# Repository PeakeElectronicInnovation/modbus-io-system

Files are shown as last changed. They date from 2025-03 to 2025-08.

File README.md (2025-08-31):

# Modbus IO System

A comprehensive industrial IoT system for temperature monitoring and control, featuring a central controller with web interface and multiple specialized IO boards for thermocouple measurement.

## System Overview

The Modbus IO System consists of a central **Controller** that manages multiple **IO Boards** via Modbus RTU communication. The system provides real-time temperature monitoring, data logging, alarm management, and a modern web-based dashboard for configuration and monitoring.

## System Components

### 1. Modbus IO Controller
- **MCU**: Raspberry Pi RP2040 (dual-core ARM Cortex-M0+)
- **Storage**: 16MB Flash, 1MB LittleFS filesystem
- **Connectivity**: Ethernet, dual RS485 ports, SD card
- **Features**: Web dashboard, data logging, NTP time sync

### 2. Thermocouple Interface (Isolated)
- **MCU**: AVR64DD32 microcontroller
- **Sensor IC**: MCP9601 (8 channels with fault detection)
- **Features**: Safety-critical standalone operation, open/short circuit detection, galvanic isolation
- **Applications**: Temperature safety cutoff systems, industrial process alarms

### 3. Thermocouple Interface (Non-Isolated)
- **MCU**: AVR64DD32 microcontroller  
- **Sensor IC**: MCP9600 (8 channels, basic functionality)
- **Features**: Safety-critical standalone operation for grounded thermocouples
- **Applications**: Temperature safety systems, laboratory alarms, HVAC safety cutoffs

## Key Features

### Web Dashboard
- Real-time temperature monitoring with interactive charts
- Board configuration and management
- Alarm setup and monitoring
- Data export and analysis tools

### Data Management
- High-resolution temperature logging to SD card
- Configurable recording intervals per channel
- CSV export functionality
- Historical data visualization

### Modbus Integration
- Standard Modbus RTU protocol
- Auto-discovery and configuration
- Support for up to 16 IO boards per RS485 bus
- Comprehensive register mapping

### Safety & Reliability
- **Standalone Operation**: IO boards operate independently for safety-critical applications
- **Autonomous Alarms**: Temperature cutoffs function even if controller connection is lost
- Watchdog timers and error recovery
- Power supply monitoring
- Communication fault detection
- Configuration backup and restore

## Quick Start

1. **Power the system** - Connect 24V power supply to controller
2. **Network setup** - Connect Ethernet cable and access web interface
3. **Add IO boards** - Connect boards via RS485 and use auto-discovery
4. **Configure channels** - Set thermocouple types, alarms, and recording preferences
5. **Monitor data** - View real-time temperatures and historical trends

## Technical Specifications

| Component | Controller | TC Interface | TC Non-Isolated |
|---|---|---|---|
| MCU | RP2040 @ 250MHz | AVR64DD32 @ 24MHz | AVR64DD32 @ 24MHz |
| Flash | 16MB | 64KB | 64KB |
| RAM | 264KB | 8KB | 8KB |
| Channels | - | 8 TC inputs | 8 TC inputs |
| Isolation | - | Galvanic | None |
| Fault Detection | - | Open/Short | None |
| Power | 24V | 24V | 24V |

## Development

Each component is a separate PlatformIO project:
- `modbus-io-controller/` - Main controller firmware
- `modbus-io-thermocouple-interface/` - Isolated TC board firmware  
- `modbus-io-thermocouple-non-isolated-interface/` - Non-isolated TC board firmware

## License

Copyright © 2025 Peake Electronic Innovation. All rights reserved.

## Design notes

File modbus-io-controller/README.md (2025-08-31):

# Modbus IO Controller

The central hub of the Modbus IO System, built around the Raspberry Pi RP2040 microcontroller. This controller manages multiple IO boards via dual RS485 buses and provides a comprehensive web interface for system monitoring and configuration.

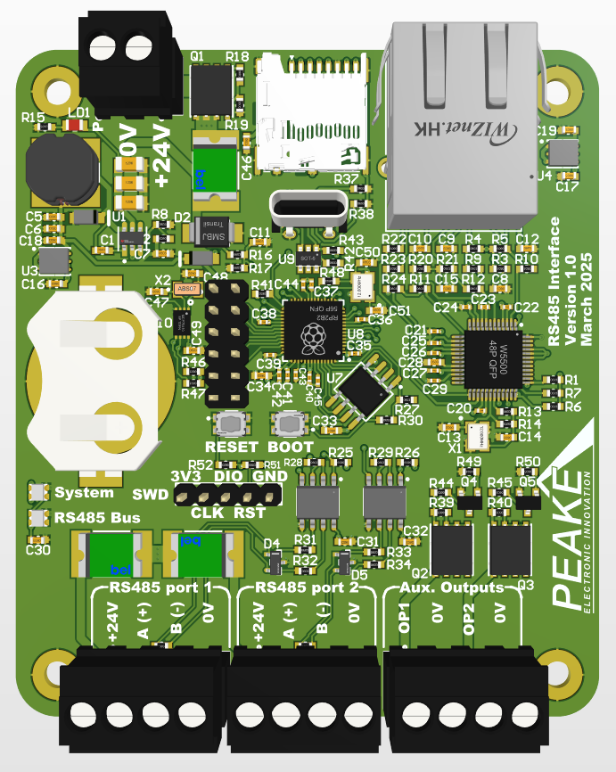
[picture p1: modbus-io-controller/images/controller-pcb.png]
Controller PCB


## Overview

The Modbus IO Controller serves as the master device in a distributed IO system, coordinating communication with up to 32 slave devices across two independent RS485 networks. It features a modern web interface, data logging capabilities, and robust networking features.

## Hardware Specifications

### Microcontroller
- **MCU**: Raspberry Pi RP2040
- **Architecture**: Dual-core ARM Cortex-M0+ @ 250MHz
- **Flash Memory**: 16MB (W25Q128)
- **RAM**: 264KB SRAM
- **Filesystem**: 1MB LittleFS partition

### Connectivity
- **Ethernet**: W5500 controller with RJ45 connector
- **RS485**: Dual isolated ports with automatic direction control
- **USB**: USB-C connector for programming and debugging
- **SD Card**: MicroSD slot for data logging

### Power System
- **Input**: 24VDC via terminal block
- **Regulation**: Switching regulator to 3.3V
- **Monitoring**: Voltage feedback with over/under voltage detection
- **Consumption**: ~2W typical operation

### Indicators
- **Status LEDs**: 2x WS2812B RGB LEDs for system and communication status
- **Power LED**: Green LED for power indication

## Key Features

### Web Interface
- **Dashboard**: Real-time temperature monitoring with interactive charts
- **Configuration**: Board management, channel setup, alarm configuration
- **Data Export**: CSV download of historical data
- **System Settings**: Network configuration, time sync
- **Responsive Design**: Works on desktop, tablet, and mobile devices

### Data Logging
- **Storage**: High-capacity SD card support (up to 32GB)
- **Format**: CSV files with timestamp, board ID, channel, temperature
- **Intervals**: Configurable per channel (1 second to 24 hours)
- **Management**: Automatic file rotation and storage monitoring

### Network Features
- **DHCP/Static IP**: Automatic or manual network configuration
- **NTP Sync**: Automatic time synchronization
- **mDNS**: Device discovery via hostname.local

### Modbus Management
- **Auto-Discovery**: Automatic detection of connected IO boards
- **Configuration**: Web-based setup of board parameters
- **Monitoring**: Real-time communication status and error detection
- **Addressing**: Automatic slave ID assignment and conflict resolution

## Software Architecture

### Dual-Core Design
- **Core 0**: Network management, web server, Modbus TCP
- **Core 1**: IO management, data logging, system monitoring

### Key Modules
- **Network Manager**: Ethernet, WiFi, and protocol handling
- **IO Core**: Board discovery, configuration, and data collection
- **Storage Manager**: SD card operations and data logging
- **Time Manager**: NTP synchronization and RTC management
- **Power Manager**: Voltage monitoring and power state management

## Pin Configuration

### RS485 Interfaces
- **Bus 1**: GPIO pins for UART1 with automatic DE/RE control
- **Bus 2**: GPIO pins for UART2 with automatic DE/RE control

### System Interfaces
- **I2C**: Real-time clock (MCP79410) communication
- **SPI**: Ethernet controller and SD card interfaces
- **Status LEDs**: WS2812B data line
- **Power Monitor**: ADC input for voltage feedback

## Development Setup

### Prerequisites
- PlatformIO IDE or CLI
- USB-C cable for programming
- 24V power supply for testing

### Build Process
```bash
# Clone repository
git clone <repository-url>
cd modbus-io-system/modbus-io-controller

# Build firmware
pio run

# Build filesystem image
pio run -t buildfs

# Upload firmware
pio run -t upload

# Upload filesystem
pio run -t uploadfs
```

### Web Asset Optimization
The build process includes automatic minification of web assets:
- **JavaScript**: Minified from 137KB to 18KB
- **HTML**: Compressed from 35KB to 13KB  
- **Charts**: Custom lightweight SVG implementation (14KB vs 207KB Chart.js)

## Configuration

### Network Setup
Access the web interface at the device IP address. Default configuration:
- **DHCP**: Enabled by default
- **Fallback IP**: 192.168.1.100
- **Hostname**: modbus-controller.local

### Board Management
1. Connect IO boards via RS485
2. Use "Scan for Boards" in web interface
3. Configure board settings and channel parameters
4. Enable data logging as needed

## Troubleshooting

### Common Issues
- **No web interface**: Check Ethernet connection and IP configuration
- **Board not detected**: Verify RS485 wiring and termination
- **Data logging fails**: Check SD card insertion and formatting
- **Time sync issues**: Verify NTP server accessibility

### LED Status Indicators
- **Status LED** (LED 1):
  - Green: System OK
  - Red: System error
  - Blue: Unconfigured
  - Orange: Warning
- **Communication LED** (LED 2):
  - Green: Active communication
  - Red: Communication error
  - Off: No activity

## Technical Notes

### Memory Optimization
The system implements advanced memory management techniques:
- **Binary Configuration Storage**: 90% reduction in RAM usage
- **Compressed Web Assets**: 88% reduction in flash usage
- **Efficient Data Structures**: Optimized for RP2040 constraints

### Performance
- **Scan Rate**: Up to 100Hz per channel depending on configuration
- **Web Response**: <100ms for most operations
- **Data Logging**: Sustained 1MB/hour with 32 channels @ 1Hz

## Hardware Revision

**Current Version**: v1.0 (March 2025)
- Initial production release
- Optimized power supply design
- Enhanced EMI protection

## Support

For technical support and documentation updates, contact Peake Electronic Innovation.

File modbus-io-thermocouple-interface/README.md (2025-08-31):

# Thermocouple Interface (Isolated)

An 8-channel thermocouple measurement board with galvanic isolation and advanced fault detection capabilities. Built around the AVR64DD32 microcontroller and MCP9601 thermocouple-to-digital converters.

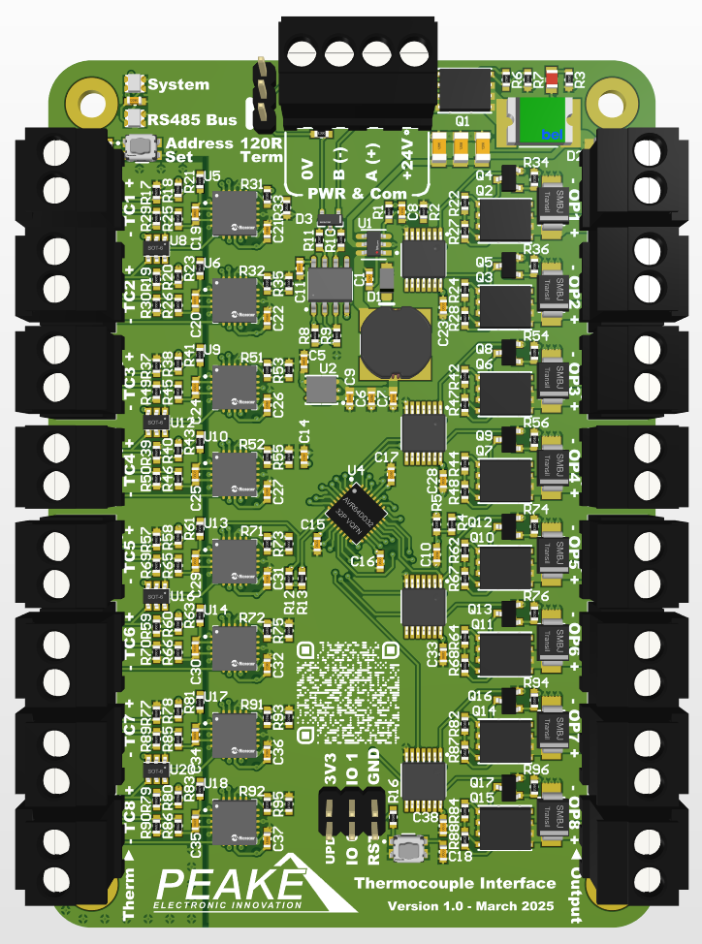
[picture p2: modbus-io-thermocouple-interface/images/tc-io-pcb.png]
Thermocouple Interface PCB


## Overview

This board provides high-accuracy thermocouple measurement with comprehensive fault detection for safety-critical industrial applications. **The board operates autonomously** - once configured, it continues to provide temperature monitoring and safety cutoffs even if communication with the controller is lost. Each channel features galvanic isolation and can detect open circuits, short circuits, and provide temperature alarms with configurable setpoints.

## Hardware Specifications

### Microcontroller
- **MCU**: AVR64DD32 (64KB Flash, 8KB RAM)
- **Architecture**: 8-bit AVR @ 24MHz
- **Communication**: Modbus RTU slave via RS485
- **Programming**: UPDI interface

### Thermocouple Interface
- **IC**: MCP9601 (8 channels)
- **Resolution**: 0.0625°C (16-bit)
- **Accuracy**: ±1.5°C (typical)
- **Cold Junction**: Integrated compensation
- **Sampling Rate**: Up to 4 samples/second per channel

### Supported Thermocouple Types
- **Type K**: -200°C to +1372°C
- **Type J**: -210°C to +1200°C  
- **Type T**: -200°C to +400°C
- **Type N**: -200°C to +1300°C
- **Type S**: -50°C to +1768°C
- **Type E**: -200°C to +1000°C
- **Type B**: +250°C to +1820°C
- **Type R**: -50°C to +1768°C

### Fault Detection
- **Open Circuit**: Detects broken or disconnected thermocouples
- **Short Circuit**: Detects shorted thermocouple inputs
- **Over/Under Range**: Temperature readings outside sensor limits
- **Communication**: I2C bus error detection

### Power System
- **Input**: 24VDC via terminal block
- **Isolation**: Galvanic isolation between measurement and digital circuits
- **Consumption**: ~3W typical operation
- **Protection**: Reverse polarity and overvoltage protection

## Key Features

### Advanced Measurement
- **Multi-Type Support**: All standard thermocouple types
- **Auto-Calibration**: Automatic cold junction compensation
- **High Resolution**: 16-bit ADC with 0.0625°C resolution
- **Fast Response**: Configurable sampling rates up to 4Hz

### Alarm Management
- **Configurable Setpoints**: Per-channel temperature alarms
- **Hysteresis**: Prevents alarm chatter
- **Latch/Auto-Clear**: Configurable alarm behavior
- **Rising/Falling Edge**: Configurable alarm direction

### Safety Output Control
- **8 Relay Outputs**: One per thermocouple channel for safety cutoffs
- **Autonomous Operation**: Outputs function independently of controller connection
- **Alarm Driven**: Automatic safety cutoffs based on temperature thresholds
- **Manual Override**: Direct control via Modbus commands when connected
- **Feedback**: Output state monitoring

### Status Indication
- **Dual LEDs**: WS2812B RGB LEDs for status and communication
- **Visual Feedback**: Color-coded status indication
- **Address Button**: Manual Modbus address configuration

## Modbus Register Map

### Input Registers (Read-Only)
| Address | Description | Units | Range |
|---|---|---|---|
| 0-7 | Channel 0-7 Temperature | 0.1°C | -2000 to +15000 |
| 8-15 | Channel 0-7 Cold Junction | 0.1°C | -400 to +1250 |
| 16-23 | Channel 0-7 Delta Temperature | 0.1°C | -2000 to +15000 |

### Holding Registers (Read/Write)
| Address | Description | Units | Range |
|---|---|---|---|
| 0 | Status Register | Bitmap | - |
| 1 | Board Type ID | - | 0x0002 |
| 2 | Slave ID | - | 1-244 |
| 3-10 | Channel 0-7 TC Type | - | 0-7 |
| 11-18 | Channel 0-7 Alert Setpoint | 0.1°C | -400 to +15000 |
| 19-26 | Channel 0-7 Alert Hysteresis | 0.1°C | 0-255 |
| 27-42 | Board Name | ASCII | 32 chars |

### Coils (Read/Write)
| Address | Description |
|---|---|
| 0-7 | Channel 0-7 Output Enable |
| 8-15 | Channel 0-7 Alert Enable |
| 16-23 | Channel 0-7 Alert Latch |
| 24-31 | Channel 0-7 Alert Edge |
| 32-39 | Channel 0-7 Latch Reset |

### Discrete Inputs (Read-Only)
| Address | Description |
|---|---|
| 0-7 | Channel 0-7 Output State |
| 8-15 | Channel 0-7 Alert State |
| 16-23 | Channel 0-7 Open Circuit |
| 24-31 | Channel 0-7 Short Circuit |

## Configuration

### Initial Setup
1. **Power Connection**: Apply 24VDC to power terminals
2. **RS485 Connection**: Connect to Modbus master via A/B terminals
3. **Address Assignment**: Hold address button for 3 seconds to enter config mode
4. **Thermocouple Connection**: Connect thermocouples to TC0-TC7 terminals

### Channel Configuration
Each channel can be independently configured:
- **Thermocouple Type**: Select appropriate type for sensor
- **Alert Setpoint**: Temperature threshold for alarm
- **Alert Hysteresis**: Deadband to prevent chatter
- **Output Control**: Enable/disable relay output
- **Alarm Behavior**: Latch or auto-clear, rising or falling edge

### EEPROM Storage
Configuration is automatically saved to EEPROM:
- **Address 0**: Validation byte (0xAA)
- **Address 1-12**: Modbus configuration
- **Address 16-95**: Thermocouple channel configurations

## Development

### Build Environment
```bash
# Navigate to project directory
cd modbus-io-thermocouple-interface

# Build firmware
pio run -e Upload_UPDI

# Upload via UPDI programmer
pio run -e Upload_UPDI -t upload
```

### Programming Interface
- **UPDI**: Single-wire programming interface
- **Programmer**: Atmel-ICE or compatible
- **Bootloader**: Optional UART bootloader support

### Debug Features
- **Serial Output**: 115200 baud debug information
- **Status Monitoring**: Real-time system status via serial
- **Configuration Echo**: Displays loaded configuration on startup

## Installation

### Mechanical
- **Mounting**: 4x M3 mounting holes
- **Enclosure**: DIN rail compatible housing
- **Dimensions**: 100mm x 80mm PCB

### Electrical
- **Power**: 24VDC ±10% via screw terminals
- **RS485**: 2-wire interface with 120Ω termination
- **Thermocouples**: Standard miniature connectors
- **Outputs**: Relay contacts rated for 250VAC/5A

## Safety Considerations

### Isolation
- **Galvanic Isolation**: Complete isolation between measurement and communication
- **Voltage Rating**: 1000V isolation barrier
- **Safety Standards**: Designed for industrial safety requirements

### Fault Protection
- **Input Protection**: ESD protection on all thermocouple inputs
- **Power Protection**: Reverse polarity and overvoltage protection
- **Thermal Protection**: Automatic shutdown on overtemperature

## Troubleshooting

### LED Status Codes
- **Status LED** (LED 1):
  - **Solid Green**: System OK, Modbus configured
  - **Pulsing Red**: System error (I2C, power, etc.)
  - **Pulsing Blue**: Unconfigured, waiting for address assignment
- **Communication LED** (LED 2):
  - **Brief Green**: Successful Modbus communication
  - **Brief Red**: Modbus communication error
  - **Off**: No communication activity

### Common Issues
- **No temperature reading**: Check thermocouple connections and type setting
- **Open circuit fault**: Verify thermocouple continuity
- **Communication timeout**: Check RS485 wiring and termination
- **Address conflicts**: Use address button to reconfigure slave ID

## Hardware Revision

**Current Version**: v1.0 (March 2025)
- Initial production release
- MCP9601 with full fault detection
- Galvanic isolation design
- Enhanced EMI filtering

## Applications

### Safety-Critical Industrial Applications
- **Furnace Safety Systems**: Emergency shutdown on overtemperature
- **Chemical Process Safety**: Autonomous temperature monitoring and cutoffs
- **Heat Treatment Control**: Independent safety interlocks
- **Boiler Protection**: Steam system safety shutdowns

### Laboratory Equipment
- Research instrumentation
- Calibration systems
- Environmental chambers
- Materials testing

## Technical Support

For technical support, schematic information, and application notes, contact Peake Electronic Innovation.

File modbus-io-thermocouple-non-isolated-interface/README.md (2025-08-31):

# Thermocouple Interface (Non-Isolated)

An 8-channel thermocouple measurement board designed for cost-effective temperature monitoring with grounded thermocouples. Built around the AVR64DD32 microcontroller and MCP9600 thermocouple-to-digital converters.

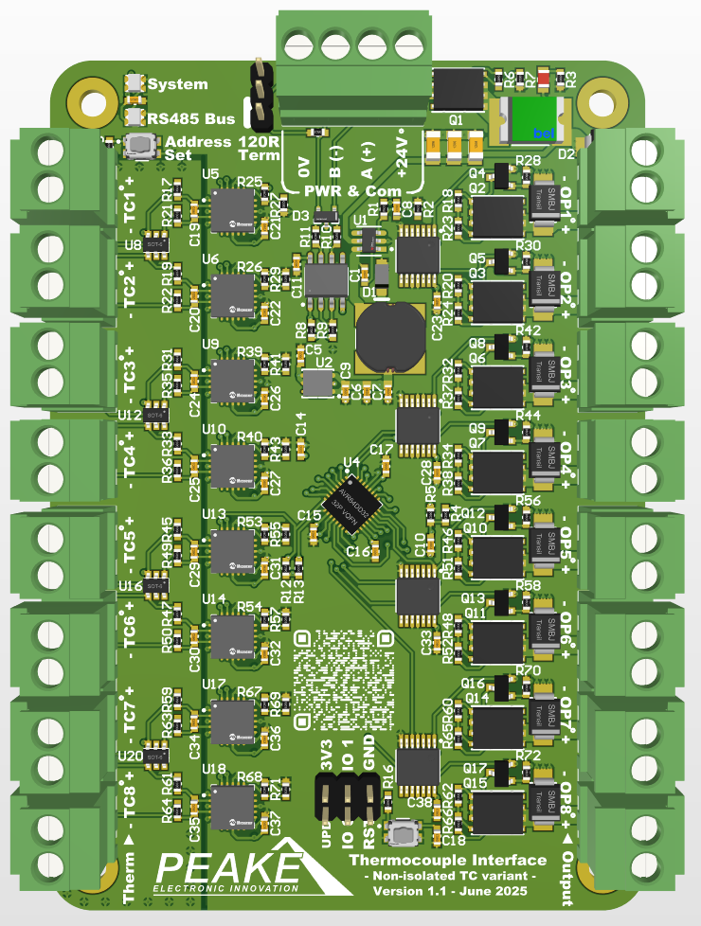
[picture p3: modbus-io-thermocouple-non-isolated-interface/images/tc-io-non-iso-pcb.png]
Thermocouple Non-Isolated Interface PCB


## Overview

This board provides accurate thermocouple measurement for safety-critical applications where galvanic isolation is not required. **The board operates autonomously** - once configured, it continues to provide temperature monitoring and safety cutoffs even if communication with the controller is lost. It's optimized for grounded thermocouple systems and offers the same measurement capabilities as the isolated version but without fault detection, making it ideal for laboratory and HVAC safety applications.

## Hardware Specifications

### Microcontroller
- **MCU**: AVR64DD32 (64KB Flash, 8KB RAM)
- **Architecture**: 8-bit AVR @ 24MHz
- **Communication**: Modbus RTU slave via RS485
- **Programming**: UPDI interface

### Thermocouple Interface
- **IC**: MCP9600 (8 channels)
- **Resolution**: 0.0625°C (16-bit)
- **Accuracy**: ±1.5°C (typical)
- **Cold Junction**: Integrated compensation
- **Sampling Rate**: Up to 4 samples/second per channel

### Supported Thermocouple Types
- **Type K**: -200°C to +1372°C
- **Type J**: -210°C to +1200°C  
- **Type T**: -200°C to +400°C
- **Type N**: -200°C to +1300°C
- **Type S**: -50°C to +1768°C
- **Type E**: -200°C to +1000°C
- **Type B**: +250°C to +1820°C
- **Type R**: -50°C to +1768°C

### Key Differences from Isolated Version
- **No Galvanic Isolation**: Direct connection to measurement circuits
- **No Fault Detection**: Cannot detect open or short circuits
- **MCP9600 IC**: Basic thermocouple converter without fault detection
- **Grounded TC Compatible**: Suitable for grounded thermocouple applications
- **Lower Cost**: Simplified design reduces manufacturing cost

### Power System
- **Input**: 24VDC via terminal block
- **Consumption**: ~2.5W typical operation
- **Protection**: Reverse polarity and overvoltage protection

## Key Features

### Temperature Measurement
- **Multi-Type Support**: All standard thermocouple types
- **Auto-Calibration**: Automatic cold junction compensation
- **High Resolution**: 16-bit ADC with 0.0625°C resolution
- **Fast Response**: Configurable sampling rates up to 4Hz

### Alarm Management
- **Configurable Setpoints**: Per-channel temperature alarms
- **Hysteresis**: Prevents alarm chatter
- **Latch/Auto-Clear**: Configurable alarm behavior
- **Rising/Falling Edge**: Configurable alarm direction

### Safety Output Control
- **8 Relay Outputs**: One per thermocouple channel for safety cutoffs
- **Autonomous Operation**: Outputs function independently of controller connection
- **Alarm Driven**: Automatic safety cutoffs based on temperature thresholds
- **Manual Override**: Direct control via Modbus commands when connected
- **Feedback**: Output state monitoring

### Status Indication
- **Dual LEDs**: WS2812B RGB LEDs for status and communication
- **Visual Feedback**: Color-coded status indication
- **Address Button**: Manual Modbus address configuration

## Modbus Register Map

### Input Registers (Read-Only)
| Address | Description | Units | Range |
|---|---|---|---|
| 0-7 | Channel 0-7 Temperature | 0.1°C | -2000 to +15000 |
| 8-15 | Channel 0-7 Cold Junction | 0.1°C | -400 to +1250 |
| 16-23 | Channel 0-7 Delta Temperature | 0.1°C | -2000 to +15000 |

### Holding Registers (Read/Write)
| Address | Description | Units | Range |
|---|---|---|---|
| 0 | Status Register | Bitmap | - |
| 1 | Board Type ID | - | 0x0002 |
| 2 | Slave ID | - | 1-244 |
| 3-10 | Channel 0-7 TC Type | - | 0-7 |
| 11-18 | Channel 0-7 Alert Setpoint | 0.1°C | -400 to +15000 |
| 19-26 | Channel 0-7 Alert Hysteresis | 0.1°C | 0-255 |
| 27-42 | Board Name | ASCII | 32 chars |

### Coils (Read/Write)
| Address | Description |
|---|---|
| 0-7 | Channel 0-7 Output Enable |
| 8-15 | Channel 0-7 Alert Enable |
| 16-23 | Channel 0-7 Alert Latch |
| 24-31 | Channel 0-7 Alert Edge |
| 32-39 | Channel 0-7 Latch Reset |

### Discrete Inputs (Read-Only)
| Address | Description |
|---|---|
| 0-7 | Channel 0-7 Output State |
| 8-15 | Channel 0-7 Alert State |
| 16-23 | Reserved (No Open Circuit Detection) |
| 24-31 | Reserved (No Short Circuit Detection) |

## Configuration

### Initial Setup
1. **Power Connection**: Apply 24VDC to power terminals
2. **RS485 Connection**: Connect to Modbus master via A/B terminals
3. **Address Assignment**: Hold address button for 3 seconds to enter config mode
4. **Thermocouple Connection**: Connect grounded thermocouples to TC0-TC7 terminals

### Channel Configuration
Each channel can be independently configured:
- **Thermocouple Type**: Select appropriate type for sensor
- **Alert Setpoint**: Temperature threshold for alarm
- **Alert Hysteresis**: Deadband to prevent chatter
- **Output Control**: Enable/disable relay output
- **Alarm Behavior**: Latch or auto-clear, rising or falling edge

### EEPROM Storage
Configuration is automatically saved to EEPROM:
- **Address 0**: Validation byte (0xAA)
- **Address 1-12**: Modbus configuration
- **Address 16-95**: Thermocouple channel configurations

## Development

### Build Environment
```bash
# Navigate to project directory
cd modbus-io-thermocouple-non-isolated-interface

# Build firmware
pio run -e Upload_UPDI

# Upload via UPDI programmer
pio run -e Upload_UPDI -t upload
```

### Programming Interface
- **UPDI**: Single-wire programming interface
- **Programmer**: Atmel-ICE or compatible
- **Bootloader**: Optional UART bootloader support

### Debug Features
- **Serial Output**: 115200 baud debug information
- **Status Monitoring**: Real-time system status via serial
- **Configuration Echo**: Displays loaded configuration on startup

## Installation

### Mechanical
- **Mounting**: 4x M3 mounting holes
- **Enclosure**: DIN rail compatible housing
- **Dimensions**: 100mm x 80mm PCB

### Electrical
- **Power**: 24VDC ±10% via screw terminals
- **RS485**: 2-wire interface with 120Ω termination
- **Thermocouples**: Standard miniature connectors (grounded types)
- **Outputs**: Relay contacts rated for 250VAC/5A

## Applications

### Laboratory Safety Systems
- **Research Instruments**: Autonomous temperature safety monitoring
- **Calibration Systems**: Independent temperature cutoffs
- **Environmental Chambers**: Safety interlocks for climate control
- **Materials Testing**: Thermal runaway protection

### HVAC Safety Applications
- **Building Automation**: Zone temperature safety cutoffs
- **Boiler Systems**: Independent overtemperature protection
- **Air Handling Units**: Safety shutdowns for supply/return air
- **Heat Exchangers**: Autonomous thermal protection

### Food & Beverage
- **Process Monitoring**: Cooking and pasteurization temperatures
- **Cold Storage**: Refrigeration system monitoring
- **Brewing**: Fermentation temperature control
- **Quality Control**: Product temperature verification

## Limitations

### No Fault Detection
Unlike the isolated version, this board cannot detect:
- Open circuit conditions (broken thermocouples)
- Short circuit conditions (shorted inputs)
- Thermocouple degradation

### Grounding Requirements
- **Common Ground**: All thermocouples must share common ground with system
- **Ground Loops**: Potential for noise in multi-point grounded systems
- **Isolation**: No galvanic isolation between channels

## Troubleshooting

### LED Status Codes
- **Status LED** (LED 1):
  - **Solid Green**: System OK, Modbus configured
  - **Pulsing Red**: System error (I2C, power, etc.)
  - **Pulsing Blue**: Unconfigured, waiting for address assignment
- **Communication LED** (LED 2):
  - **Brief Green**: Successful Modbus communication
  - **Brief Red**: Modbus communication error
  - **Off**: No communication activity

### Common Issues
- **Erratic readings**: Check for ground loops or EMI
- **No temperature reading**: Verify thermocouple type setting
- **Communication timeout**: Check RS485 wiring and termination
- **Address conflicts**: Use address button to reconfigure slave ID

### Grounding Best Practices
- **Single Point Ground**: Connect all thermocouple shields to one point
- **Avoid Ground Loops**: Keep measurement and power grounds separate
- **EMI Protection**: Use shielded cables in high-noise environments

## Hardware Revision

**Current Version**: v1.1 (June 2025)
- Updated from isolated design
- MCP9600 implementation
- Optimized for grounded thermocouple applications
- Cost-reduced design

## Comparison with Isolated Version

| Feature | Isolated (MCP9601) | Non-Isolated (MCP9600) |
|---|---|---|
| Open Circuit Detection | ✓ | ✗ |
| Short Circuit Detection | ✓ | ✗ |
| Galvanic Isolation | ✓ | ✗ |
| Grounded TC Support | Limited | ✓ |
| Cost | Higher | Lower |
| Applications | Industrial | Lab/HVAC |

## Technical Support

For technical support, schematic information, and application notes, contact Peake Electronic Innovation.

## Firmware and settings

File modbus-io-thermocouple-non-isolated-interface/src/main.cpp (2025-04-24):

#include "sys_init.h"

// Early initialization code that runs before main C runtime
void __attribute__((section(".init3"))) early_init(void) {
  // Set all Port A pins high immediately after reset
  PORTA.OUTSET = 0xFF;  // Set all Port A pins high
  PORTA.DIRSET = 0xFF;  // Set all Port A pins as outputs
}

void saveConfig() {
  newDataToSave = false;
  // Save Slave ID and board name to EEPROM
  EEPROM.put(EEPROM_MODBUSCFG_ADDR, modbusHolding.slaveID);
  EEPROM.put(EEPROM_BOARDNAME_ADDR, modbusHolding.boardName);
  // Save thermocouple config to EEPROM
  for(int i = 0; i < 8; i++) {
    EEPROM.put(EEPROM_CONFIG_ADDR + (i * sizeof(tc_config_t)), tcConfig[i]);
  }
}

void getConfig() {
  // EEPROM memory map -----------------------------------------
  // 0 - EEPROM Valid Value (0xAA)
  // 1 - Modbus Config (12 bytes)
  // 16 - MCP960x Config (8 * 10 bytes)
  // -----------------------------------------------------------

  // Read configuration from EEPROM
  uint8_t valid = EEPROM.read(EEPROM_VALID_ADDR);

  // Store defaults if valid byte is not set
  if (valid != EEPROM_VALID_VALUE) {
    Serial.println("Invalid EEPROM data, initializing to default values:");
    saveConfig();
    EEPROM.write(EEPROM_VALID_ADDR, EEPROM_VALID_VALUE);
    Serial.println("Default configuration saved to EEPROM.");
  } else {
     // Load configuration from EEPROM
    Serial.println("Loading previously saved configuration from EEPROM...");
    // Slave ID:
    EEPROM.get(EEPROM_MODBUSCFG_ADDR, modbusHolding.slaveID);
    if (modbusHolding.slaveID < 245 && modbusHolding.slaveID > 0) {
      modbusInitialised = true;
      statusLedColour = LED_OK;
      Serial.printf("Modbus slave ID: %d\n", modbusHolding.slaveID);
    } else {
      statusLedColour = LED_UNCONFIGURED;
      Serial.printf("Modbus unconfigured\n");
    }
    // Board name:
    EEPROM.get(EEPROM_BOARDNAME_ADDR, modbusHolding.boardName);
    Serial.printf("Board name: %s\n", modbusHolding.boardName);
    // Thermocouple config:
    for(int i = 0; i < 8; i++) {
      EEPROM.get(EEPROM_CONFIG_ADDR + (i * sizeof(tc_config_t)), tcConfig[i]);
    }
  }

  // Store config to tc structs and modbus registers
  for(int i = 0; i < 8; i++) {
    tc[i].config.type = static_cast<MCP960x_type_t>(tcConfig[i].type);
    tc[i].config.alertSP[0] = tcConfig[i].alertSP;
    tc[i].config.alertHyst[0] = tcConfig[i].alertHyst;
    tc[i].config.alertEnable[0] = tcConfig[i].alertEnable;
    tc[i].config.alertLatch[0] = tcConfig[i].alertLatch;
    tc[i].config.alertEdge[0] = tcConfig[i].alertEdge;
    modbusHolding.type[i] = static_cast<uint16_t>(tcConfig[i].type);
    modbusHolding.alertSP[i] = tcConfig[i].alertSP;
    modbusHolding.alertHyst[i] = tcConfig[i].alertHyst;
    modbusOutSet.alertEnable[i] = tcConfig[i].alertEnable;
    modbusOutSet.alertLatch[i] = tcConfig[i].alertLatch;
    modbusOutSet.alertEdge[i] = tcConfig[i].alertEdge;
    modbusOutSet.outputEnable[i] = tcConfig[i].outputEnable;

    // Debug print
    Serial.printf("Type: %d, SD: ", modbusHolding.type[i]);
    Serial.print(modbusHolding.alertSP[i]);
    Serial.printf(", Hyst: %d, Enable: %d, Latch: %d, Edge: %d, Output Enable: %d\n", modbusHolding.alertHyst[i], modbusOutSet.alertEnable[i], modbusOutSet.alertLatch[i], modbusOutSet.alertEdge[i], modbusOutSet.outputEnable[i]);
  }
  Serial.printf("modbusHolding.boardType: %d\n", modbusHolding.boardType);
  memcpy(holdingReg, &modbusHolding, sizeof(holdingReg));
  memcpy(coil, &modbusOutSet, sizeof(coil));
  Serial.printf("After memcpy holdingReg[1]: %d\n", holdingReg[1]);
}

void setupModbus() {
  pinMode(PIN_ADDR_BTN, INPUT_PULLUP);
  bus.configureCoils(coil, 40);
  bus.configureDiscreteInputs(inputDiscrete, 32);
  bus.configureHoldingRegisters(holdingReg, 42);
  bus.configureInputRegisters(inputReg, 48);
  if (modbusInitialised) {
    bus.begin(modbusHolding.slaveID, 500000);
    commLedColour = LED_OK;
  } else {
    commLedColour = LED_OFF;
    Serial.println("Modbus not configured, hold Address button for 3 seconds to start configuration.");
  }
  Serial.printf("After setupModbus holdingReg[1]: %d\n", holdingReg[1]);
}

void setupThermocoupleInterface() {
  Wire.pins(PIN_I2C_SDA, PIN_I2C_SCL); // Set I2C pins for Wire library
  Wire.begin(); // Initialize I2C bus
  Wire.setClock(50000);
  bool error = false;
  for (int i = 0; i < 8; i++) {
    uint8_t deviceID = tc[i].begin(); // Initialize each MCP960x thermocouple interface
    if (deviceID == 0) {
      Serial.printf("Failed to initialize MCP960x at address 0x6%x\n", i);
      error = true;
    } else {
      Serial.printf("MCP960x initialized successfully! Device at address 0x6%x has device ID: 0x%02x\n", i, deviceID);
      if (!tc[i].setConfig()) { // Set the configuration for each MCP960x
        Serial.printf("Failed to set configuration for MCP960x at address 0x6%x\n", i);
        error = true;
      } else {
        Serial.printf("Configuration set successfully for MCP960x at address 0x6%x\n", i);
        tc[i].printConfig();
      }
    }
  }
  statusLedColour = error ? LED_ERROR : modbusInitialised ? LED_OK : LED_UNCONFIGURED;

  if (error) {
    Serial.println("Error initializing MCP960x devices. Check connections and power supply.");
    leds.setPixelColor(0, LED_ERROR); // Set the first LED to error color
    leds.show(); // Update the LEDs
    delay(2000);
    _PROTECTED_WRITE(RSTCTRL.SWRR,1);
  }

  // Enable outputs
  for (int i = 0; i < 8; i++) {
    pinMode(enablePin[i], OUTPUT);
    digitalWrite(enablePin[i], !modbusOutSet.outputEnable[i]);
    Serial.printf("Out Enable %d is: %i\n", i, modbusOutSet.outputEnable[i]);
    Serial.printf("Output %d is: %s\n", i, digitalRead(enablePin[i]) ? "HIGH" : "LOW");
  }
}

void readAll() {
  if (!modbusInitialised) return;
  bool error = false;
  // Read data from all MCP9601 ICs and check output states
  for (int i = 0; i < 8; i++) {
    modbusInput.temperature[i] = tc[i].readTemperature();
    modbusInput.coldJunction[i] = tc[i].readColdJunctionTemperature();
    modbusInput.deltaJunction[i] = tc[i].readDeltaTemperature();
    if (tc[i].updateStatus() == 0xFF) error = true;
    modbusFlag.outputState[i] = digitalRead(outputFBpin[i]); // Read the output state from the corresponding pin
    modbusFlag.alertState[i] = tc[i].status.alert[0];
    modbusFlag.openCircuit[i] = tc[i].status.openCircuit;
    modbusFlag.shortCircuit[i] = tc[i].status.shortCircuit;  
  }
  status.I2CError = error;
  // Copy data to modbus registers (read only)
  memcpy(inputDiscrete, &modbusFlag, sizeof(modbusFlag)); // Copy the modbusFlag struct to the inputDiscrete array
  memcpy(inputReg, &modbusInput, sizeof(modbusInput)); // Copy the modbusInput struct to the inputReg array
}

void setupLEDs() {
  // Initialize the LEDs
  leds.begin();
  leds.setBrightness(50); // Set brightness to 50%
  leds.setPixelColor(0, LED_STARTUP); // Set the first LED to the startup color
  leds.setPixelColor(1, LED_OFF); // Set the second LED to off
  leds.show(); // Update the LEDs to show the new colors
  Serial.println("LEDs initialised");
  ledPulseTime = millis() + ledPulseDelay;
}

void setupVPSU() {
  analogReference(PSU_FB_VREF);
  analogReadResolution(12);
}

void handleStatus() {
  holdingReg[0] = (status.PSUvoltage << 4) | (status.PSUError << 2) | (status.I2CError << 1) | status.modbusError;
  uint32_t tempColour = statusLedColour;
  if (status.PSUError || status.I2CError || status.modbusError) tempColour = LED_ERROR;
  if (millis() >= ledPulseTime) {
    if (ledState) leds.setPixelColor(0, LED_OFF);
    else leds.setPixelColor(0, tempColour);
    ledState = !ledState;
    leds.show();
    ledPulseTime += ledPulseDelay;
  }
}

void handleVPSU() {
  int raw = analogRead(PIN_PS_FB);
  float volts = raw * PSU_FB_RAW_TO_V;
  if (volts > PSU_VOLTAGE_MAX || volts < PSU_VOLTAGE_MIN) status.PSUError = true;
  else status.PSUError = false;
  status.PSUvoltage = static_cast<uint16_t>(volts * 10);
}

void handleModbus() {
  if (!modbusInitialised  && !waitingForModbusConfig) return;
  int FC = bus.poll();
  if (FC == 0) {
    if (!waitingForModbusConfig) {
      leds.setPixelColor(1, LED_OFF);
      leds.show();
    }
    return; // No Modbus request received
  }
  if (FC < 0) {
    Serial.printf("Modbus comm error\n");
    status.modbusError = true;
    leds.setPixelColor(1, LED_ERROR);
    leds.show();
    return; // Modbus error
  }
  status.modbusError = false;
  leds.setPixelColor(1, LED_BUSY);
  leds.show();
  Serial.printf("Modbus request recieved, function code: %d\n", FC);

  bool changed = false;

  // Handle update to coils
  if (FC == MODBUS_FC05_WRITE_SINGLE_COIL || FC == MODBUS_FC15_WRITE_MULTIPLE_COILS) {
    modbus_coil_t coilData;
    memcpy(&coilData, coil, sizeof(modbus_coil_t)); // Copy the response buffer to the coilData struct
    for (int i = 0; i < 8; i++) {
      if (coilData.outputEnable[i] != modbusOutSet.outputEnable[i]) {
        changed = true;
        modbusOutSet.outputEnable[i] = coilData.outputEnable[i];
        tcConfig[i].outputEnable = coilData.outputEnable[i];
        Serial.printf("Out Enable %d is: %i\n", i, modbusOutSet.outputEnable[i]);
        digitalWrite(enablePin[i], !modbusOutSet.outputEnable[i]);  // LOW = enabled
      }
      if (coilData.alertEnable[i] != modbusOutSet.alertEnable[i]) {
        changed = true;
        modbusOutSet.alertEnable[i] = coilData.alertEnable[i];
        tcConfig[i].alertEnable = coilData.alertEnable[i];
        Serial.printf("alert Enable %d is: %i\n", i, modbusOutSet.alertEnable[i]);
        tc[i].enableAlert(0, modbusOutSet.alertEnable[i]);          // 1 = enabled
      }
      if (coilData.alertLatch[i] != modbusOutSet.alertLatch[i]) {
        changed = true;
        modbusOutSet.alertLatch[i] = coilData.alertLatch[i];
        tcConfig[i].alertLatch = coilData.alertLatch[i];
        Serial.printf("alert Latch %d is: %i\n", i, modbusOutSet.alertLatch[i]);
        tc[i].latchAlert(0, modbusOutSet.alertLatch[i]);            // 1 = latch, 0 = auto clear (@T_alert - hysteresis value)
      }
      if (coilData.alertEdge[i] != modbusOutSet.alertEdge[i]) {
        changed = true;
        modbusOutSet.alertEdge[i] = coilData.alertEdge[i];
        tcConfig[i].alertEdge = coilData.alertEdge[i];
        Serial.printf("alert Edge %d is: %i\n", i, modbusOutSet.alertEdge[i]);
        tc[i].setAlartEdge(0, modbusOutSet.alertEdge[i]);           // 1 = alert on falling temp, 0 = alert on rising temp
      }
      if (coilData.resetLatch[i]) {
        coil[LATCH_RESET_PTR + i] = false; // Reset latch
        // Clear device alert 0 interrupt bit
        tc[i].clearAlert(0);
        Serial.printf("MCP9601 %d alert latch 0 reset\n", i);
      }
    }
  }

  // Handle update to holding registers
  if (FC == MODBUS_FC06_WRITE_SINGLE_REGISTER || FC == MODBUS_FC16_WRITE_MULTIPLE_REGISTERS) {
    if (holdingReg[1] != modbusHolding.boardType) {
      Serial.printf("----------> ERROR! Board type changed, changing back to 0x0002 <--------\n");
      holdingReg[1] = modbusHolding.boardType;  // Thermocouple IO board ID
    }
    modbus_holding_t holdingData;
    memcpy(&holdingData, holdingReg, sizeof(modbus_holding_t));
    for (int i = 0; i < 8; i++) {
      // Thermocouple Type change check, validate and apply
      if ((holdingData.type[i] <= 7) && (holdingData.type[i] != modbusHolding.type[i])) {
        changed = true;
        Serial.printf("Thermocouple %d type changed to %d\n", i, holdingData.type[i]);
        modbusHolding.type[i] = holdingData.type[i];
        tcConfig[i].type = holdingData.type[i];
        tc[i].setType(static_cast<MCP960x_type_t>(modbusHolding.type[i]));
        changed = true;
      } // ------------------------------------------------------------

      // Thermocouple alert setpoint change check, validate and apply
      if ((holdingData.alertSP[i] < 1500.0) && (holdingData.alertSP[i] > -40.0) && (holdingData.alertSP[i] != modbusHolding.alertSP[i])) {
        changed = true;
        Serial.printf("Thermocouple %d SP changed to ", i);
        Serial.println(holdingData.alertSP[i]);
        modbusHolding.alertSP[i] = holdingData.alertSP[i];
        tcConfig[i].alertSP = holdingData.alertSP[i];
        tc[i].setAlertSP(0, modbusHolding.alertSP[i]);
        changed = true;
      } // ------------------------------------------------------------

      // Thermocouple alert hysteresis change check, validate and apply
      if (holdingData.alertHyst[i] != modbusHolding.alertHyst[i]) {
        changed = true;
        Serial.printf("Thermocouple %d Hyst changed to %d\n", i, holdingData.alertHyst[i]);
        modbusHolding.alertHyst[i] = holdingData.alertHyst[i];
        tcConfig[i].alertHyst = holdingData.alertHyst[i];
        tc[i].setAlertHyst(0, modbusHolding.alertHyst[i]);
        changed = true;
      } // ------------------------------------------------------------

      // Modbus slave ID change check, validate and apply
      if ((holdingData.slaveID != modbusHolding.slaveID) && (holdingData.slaveID > 0)) {
        if ((holdingData.slaveID > 244) || (holdingData.slaveID < 1)) {
          modbusHolding.slaveID = 245;
          modbusInitialised = false;
          statusLedColour = LED_UNCONFIGURED;
          Serial.printf("Slave ID reset, Modbus unconfigured\n");
        } else {
          modbusHolding.slaveID = holdingData.slaveID;
          Serial.printf("Modbus slave ID changed to %d\n", modbusHolding.slaveID);
          bus.begin(modbusHolding.slaveID, 500000);
          modbusInitialised = true;
          statusLedColour = LED_OK;
        }
        if (waitingForModbusConfig) {
          waitingForModbusConfig = false;
          Serial.println("Modbus initialisation complete!");
        }
        changed = true;
      } // ------------------------------------------------------------

      // Modbus board name change check, validate and apply
      if (strlen(holdingData.boardName) > 0) {
        if (strcmp(holdingData.boardName, modbusHolding.boardName) != 0) {
          strncpy(modbusHolding.boardName, holdingData.boardName, sizeof(modbusHolding.boardName));
          modbusHolding.boardName[sizeof(modbusHolding.boardName) - 1] = '\0'; // Ensure null termination
          Serial.printf("Modbus board name changed to %s\n", modbusHolding.boardName);
          changed = true;
        }
      } // ------------------------------------------------------------
    }
  }
  if (changed) {
    newDataTime = millis();
    newDataToSave = true;
  }
  leds.setPixelColor(1, LED_OFF);
  leds.show();
}

void handleAddrBtn() {
  // Check if button not pressed
  if (digitalRead(PIN_ADDR_BTN)) {
    if (addrBtnPressed) {
      addrBtnPressed = false;
      addrBtnTime = 0;
      return;
    }
  }
  // Ignore if already waiting for Modbus configuration
  if (waitingForModbusConfig) return;
  if (!digitalRead(PIN_ADDR_BTN)) {
    if (!addrBtnPressed) {
      addrBtnPressed = true;
      addrBtnTime = millis();
      return;
    }
    if (addrBtnPressed && ((millis() - addrBtnTime) < 2000)) return;
    waitingForModbusConfig = true;
    modbusHolding.slaveID = 245;
    bus.begin(245, 500000);
    leds.setPixelColor(1, LED_UNCONFIGURED);
    leds.show();
    Serial.println("Modbus address set to 245, waiting for configuration.");
  }
}

void saveHandler() {
  if (newDataToSave && ((millis() - newDataTime) > saveDelay_ms)) {
    newDataToSave = false;
    Serial.print("Saving configuration to EEPROM... ");
    saveConfig();
    Serial.println("Done!");
  }
}

void setup() {
  Serial.pins(PIN_GPIO_0_TX, PIN_GPIO_1_RX); // Set RX and TX pins for Serial communication
  Serial.begin(115200);
  Serial.println("Testing AVR64DD32...");

  setupLEDs();

  setupVPSU();

  Serial.printf("Loading configuration from EEPROM...\n");
  getConfig(); // Load configuration from EEPROM

  Serial.printf("Starting Modbus interface...\n");
  setupModbus(); // Setup Modbus interface

  Serial.printf("Starting thermocouple interface 1...\n");
  setupThermocoupleInterface();
  readAll();

  Serial.printf("Modbus is %sinitialised\n", modbusInitialised ? "" : "not ");

  Serial.println("Done!");
  slowLoopTime = millis() + slowLoopDelay;
}

void loop() {
  readAll();
  handleModbus();
  handleStatus();
  handleVPSU();
  handleAddrBtn();
  saveHandler();

  if (millis() >= slowLoopTime) {
    slowLoopTime += slowLoopDelay;
    Serial.printf("VPSU: %d.%dV\n", status.PSUvoltage / 10, status.PSUvoltage % 10);
  }
}

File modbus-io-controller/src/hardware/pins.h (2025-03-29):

#pragma once

// Hardware pin definitions

// Ethernet pins
#define PIN_ETH_MISO 0
#define PIN_ETH_CS 1
#define PIN_ETH_SCK 2
#define PIN_ETH_MOSI 3
#define PIN_ETH_RST 4
#define PIN_ETH_IRQ 5

// RTC pins
#define PIN_RTC_SDA 6
#define PIN_RTC_SCL 7

// SD card pins
#define PIN_SDIO_CLK 10
#define PIN_SDIO_CMD 11
#define PIN_SDIO_D0 12
#define PIN_SD_SCK 10
#define PIN_SD_MOSI 11
#define PIN_SD_MISO 12
#define PIN_SD_D1 13
#define PIN_SD_D2 14
#define PIN_SD_CS 15
#define PIN_SD_CD 18

// RS485 bus 1 pins
#define PIN_RS485_TX_1 16
#define PIN_RS485_RX_1 17

// RS485 bus 2 pins
#define PIN_RS485_TX_2 8
#define PIN_RS485_RX_2 9

// WS2812b LED pin
#define PIN_LED_DAT 19

// Local outputs
#define PIN_ALM_LED 20
#define PIN_ALM_SOUNDER 21

// Power supply feedback
#define PIN_PSU_FB 29   // ADC 4

// Spare GPIO pins
#define PIN_GPIO_22 22
#define PIN_GPIO_23 23
#define PIN_GPIO_24 24
#define PIN_GPIO_25 25
#define PIN_GPIO_26 26  // ADC 1
#define PIN_GPIO_27 27  // ADC 2
#define PIN_GPIO_28 28  // ADC 3

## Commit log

2025-04-21 Ongoing work on board config setup and management
2025-04-22 Board enrolment mostly completed
2025-04-22 Added status monitoring and prep for board status page
2025-04-22 struct type spelling mistake correction
    [io_core.cpp, main.cpp]
2025-04-24 Fix init bug with modbus slave where init is rejected because old and new address match.
    [io_core.cpp, main.cpp]
2025-04-25 Added sensor recording pipeline
2025-04-27 Added boards config export and import function
2025-04-27 Small web interface tweaks, switched to static IP as default
2025-04-29 Bug fixes with multiple board connections
    [io_core.cpp]
2025-06-28 Non-isolated version of TCIO board added, variant without OC & SC detection for non-isolated thermocouples
2025-08-11 RAM efficiencies to increase board count - 9 boards tested
    [Safety Thermocouple Interface - IO.SchDoc, Safety Thermocouple Interface - MCU.SchDoc, Safety Thermocouple Interface - No OC detect.PrjPcb]
2025-08-11 Fixed board config export/import and extended dashboard to show up to 64 channels. Expansion boards limited to 8 max boards (for now)
2025-08-12 Added board duplicate function for faster config, auto scroll to config for new boards and config edits
2025-08-12 Added option to online boards immediately when importing config - saves having to re-initialise every board
2025-08-18 Fixed board import bug where slave ID assignment index is not updated
    [io_core.cpp, network.cpp, sys_init.h]
2025-08-18 Fixed board not initialised bug on reboot where board is not connected
    [io_core.cpp]
2025-08-23 Stop recording on board offline, re-write headers on sensor file recreation
2025-08-23 Added unique board name requirement
2025-08-31 Documentation and README update for V1.1.0 release
    [Safety Thermocouple Interface - IO.SchDoc, Safety Thermocouple Interface - MCU.SchDoc, Safety Thermocouple Interface - No OC detect.PrjPcb]
2025-09-20 Recording timing switched to RTC zero second alignment
